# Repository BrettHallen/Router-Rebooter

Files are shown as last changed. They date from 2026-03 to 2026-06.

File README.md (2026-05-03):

# Router Rebooter
Simple device to reboot my router when the NBN (National Broadband Network) stops working.<br>

This is typically when we're away from home for more than a week which means that the RING cameras & WiFi-enabled lights & powerpoints (to make it look like we're home) stop working.<br>

Yes, yes, I shouldn't be using cloud-enabled devices which will get bricked at the manufacturer's whim.  I'll work on it.<br>

And yes, there are devices that do this - they seemed a bit pricey.<br>

## Idea
The broadband router I have is a Netcomm Wireless NF18ACV that runs on 12VDC.  We got it when we originally had FTTN (fibre to the node) which runs optical fibre to a street cabinet/node and then uses the decades-old telephone copper cabling to the house.  Where we live now has FTTP (fibre to the premises) where the optical fibre runs straight to the house.  The same router still works fine so have never replaced it.<br>

I'll use an ESP32-type device to ping a reliable Internet address every minute, say a well-known DNS address like 1.1.1.1.  The ESP32 will be powered from the 12V input supply via a 5V regulator.  The power to the router will run through an NC (normally closed) relay.<br>

If there is no response for a few consecutive pings then I'll energise the relay which switches to open and disconnects the 12V to the router.<br>

After a short delay I'll then de-energise the relay and power the router back on.<br>

After another short delay whilst the router reconnects (2-3min) I'll reconnect to the WiFi network and resume pinging.

## YouTube Videos
- [Part 1: Initial build & test](https://youtu.be/Fz1aSylL9KQ)
- [Part 2: Revised PCB & Improved Firmware](https://youtu.be/78il7RK1qrU)

## Examples
This is how it works using the serial port output - here we simulate the loss of Internet by using dummy IP addresses:<br>
```
>> Brett's Router Rebooter Starting!
   (2/Apr/2026)
>> Monitoring NF18ACV
>> Timer/retry settings (DEBUG):
   Ping timer .......... 10s
   Ping retries ........ 3
   Ping retry timer .... 5s
   Power cycle timer ... 30s
   Recovery delay ...... 120s
>> Hardware initialised: Router on, OK LED on, FAILURE LED off, Ping LED off.
!! [handleHttpClients] WiFi not connected, ignoring HTTP requests.
>> Connecting to WiFi network <RouterRebootTest> ...
>> Using static IP address <192.168.128.129>
>> WiFi status = 3 (successfully connected!)
>> Connected to <RouterRebootTest> with address <192.168.128.129>
>> HTTP status page started on port 80
   Open in browser: http://192.168.128.129
>> Syncing NTP time (pool.ntp.org) ... 02/Apr/2026 18:53:07 (AEDT)
>> Pinging 1.1.1.1          Cloudflare primary   ... OK!
>> Pinging 192.168.123.123  Dummy test failure   ... failed!
>> Pinging 1.0.0.1          Cloudflare secondary ... OK!
>> Pinging 192.168.123.123  Dummy test failure   ... failed!
>> Pinging 192.168.123.123  Dummy test failure   ... failed!
>> Pinging 192.168.123.123  Dummy test failure   ... failed!
>> Pinging 192.168.123.123  Dummy test failure   ... failed!
!! No response after retries, disconnecting router power.
>> Waiting 30s before reconnecting power ...
   30s
   25s
   20s
   15s
   10s
   5s
>> Powering router back on.
>> Waiting 120s before resuming monitoring ...
   120s
   105s
   90s
   75s
   60s
   45s
   30s
   15s
>> Router recovery finished – resuming monitoring.

... and so on ...
```
And this is what it does when the Internet is fine, which should be 99.9% of the time:
```

>> Brett's Router Rebooter Starting!
   (2/Apr/2026)
>> Monitoring NF18ACV
>> Timer/retry settings:
   Ping timer .......... 1s
   Ping retries ........ 5
   Ping retry timer .... 15s
   Power cycle timer ... 30s
   Recovery delay ...... 180s
>> Hardware initialised: Router on, OK LED on, FAILURE LED off, Ping LED off.
!! [handleHttpClients] WiFi not connected, ignoring HTTP requests.
>> Connecting to WiFi network <RouterRebootTest> ...
>> Using static IP address <192.168.128.129>
>> WiFi status = 3 (successfully connected!)
>> Connected to <RouterRebootTest> with address <192.168.128.129>
>> HTTP status page started on port 80
   Open in browser: http://192.168.128.129
>> Syncing NTP time (pool.ntp.org) ... 02/Apr/2026 20:26:19 (AEDT)
>> Pinging 1.1.1.1          Cloudflare primary   ... OK!
>> Pinging 1.0.0.1          Cloudflare secondary ... OK!
>> Pinging 8.8.8.8          Google primary       ... OK!
>> Pinging 8.8.4.4          Google secondary     ... OK!
>> Pinging 9.9.9.9          Quad9 primary        ... OK!
>> Pinging 149.112.112.112  Quad9 secondary      ... OK!
>> Pinging 4.2.2.1          Level 3 primary      ... OK!
>> Pinging 4.2.2.2          Level 3 secondary    ... OK!
>> Pinging 4.2.2.3          Level 3 tertiary     ... OK!
>> Pinging 208.67.222.222   OpenDNS primary      ... OK!
>> Pinging 208.67.220.220   OpenDNS secondary    ... OK!
>> Pinging 1.1.1.1          Cloudflare primary   ... OK!
>> Pinging 1.0.0.1          Cloudflare secondary ... OK!
>> Pinging 8.8.8.8          Google primary       ... OK!
>> Pinging 8.8.4.4          Google secondary     ... OK!

... and so on ...
```

## [Firmware (Arduino Sketch)](/Firmware)
Use the Arduino IDE to compile & transfer to the ESP32.<br>

### Versions
- [Tested version](/Router-Rebooter)
- [Experimental version](/Experimental_version)

Experimental version - seems to be working fine, testing ongoing:<br>
- added support to ping IP addresses as well as FQDNs

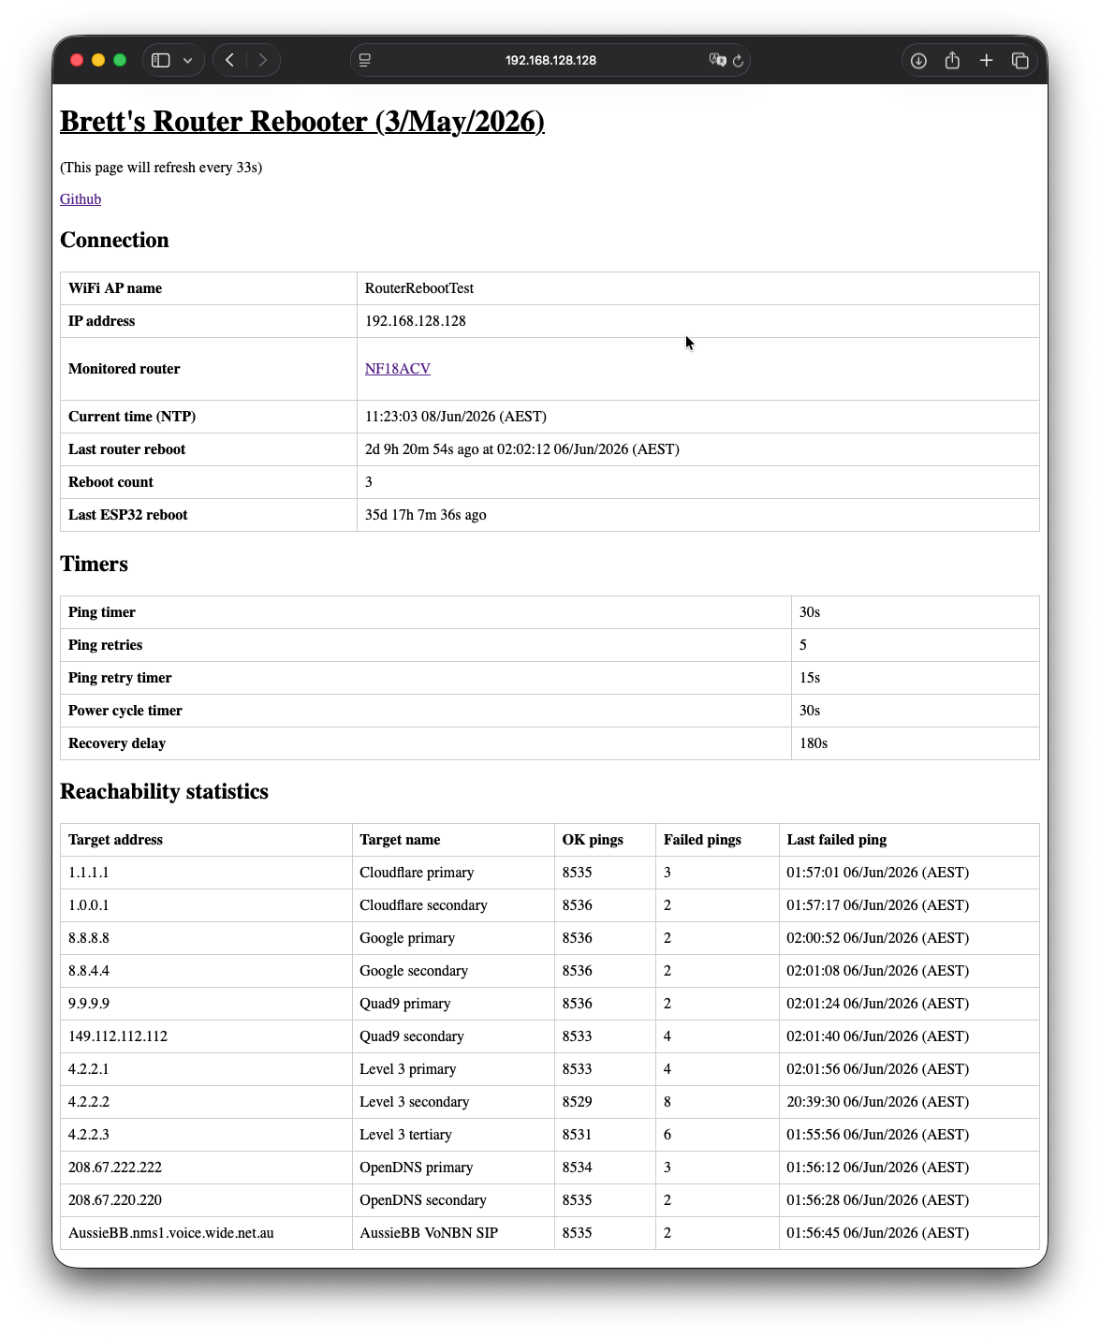
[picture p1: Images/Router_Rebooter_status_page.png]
Status page


### Required Libraries
Install via the Arduino IDE.
- [ESPping](https://github.com/dvarrel/ESPping)
- [Adafruit NeoPixel](https://github.com/adafruit/adafruit_neopixel)
- [Timezone](https://github.com/JChristensen/Timezone)

### Possible Improvements
- Send a message after the router has been rebooted (via CallMeBot to WhatsApp?)

## LED Status
There are three LEDs: the OK LED (suggested green), the FAILURE LED (suggested red) and the ESP32's built-in LED (RGB).<br>

| OK LED | FAILURE LED | ESP32 LED | Meaning |
|---|---|---|---|
| On | Off | Green/blue flashing | Connecting to WiFi |
| On | Off | Off | Everything ok, waiting to ping |
| On | Off | Blue pulse | Pinging |
| On | On | Red | Ping failed |
| Off | On | Off | Ping retries failed |
| Off | On | Green flashing | Router power cycling |
| Flashing | Flashing | Red/green flashing  | Waiting for router to recover  | 

## Hardware
There's currently two versions:
- [Rev. B](/KiCad/RevB) minor corrections of my original design with 2.1mm DC sockets and vertically mounted regulator 
- [Rev. D](/KiCad/RevC) removes the 2.1mm DC sockets, lies the 5V regulator down and adds regulator output bypass for the ESP32 when connected via serial/USB

### Parts
- OMRON GL5E-1-VD relay (or similar)
- ESP32-C3-Zero development board (Waveshare)
- 10µF capacitor for the ESP32 power - could probably be left off (short pins)
- One 7805-type 5V regulator (i.e. [EzSBC's PSU2-5](https://ezsbc.shop/products/psu2-5-5v-1amp-three-pin-regulator)) to power the ESP. I am using a switching regulator so don't have any provision for heatsinking a linear regulator.
- Two 2.1mm DC power sockets to pass through the 12VDC
- Some other bits (2N2222 transistor, 1KΩ resistor, 1N4148 diode) to connect the relay coil to the ESP32
- 2-pin header to disconnect 5V regulator when ESP32 is connected to USB for testing to avoid connecting two power supplies
- Four M3 screws to mount it somehow

I've sized the PCB (62x49mm) to fit an 83x54x31mm Jiffy Box [(Jaycar HB6015)](https://www.jaycar.com.au/jiffy-box-black-83-x-54-x-31mm/p/HB6015).<br>

Waveshare ESP32-C3-Zero symbol/footprint/3D model from:<br>
https://github.com/jonathanadams/KiCad-Waveshare-ESP32

## Images
### Rev A. version built
The green OK LED indicates normal operation of the router and the blue ESP32 LED indicates it's currently sending a test ping to test reachability.

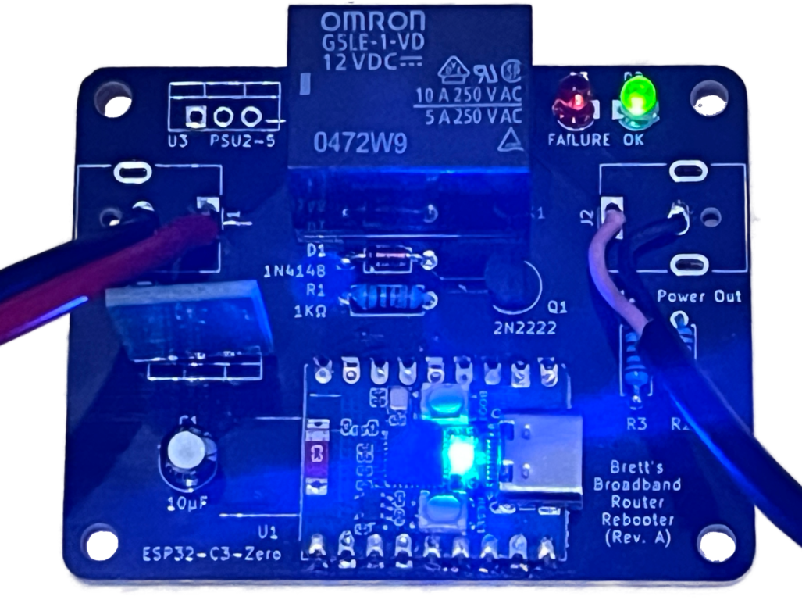
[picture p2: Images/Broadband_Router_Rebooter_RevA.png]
Rev A under test


### Rev. C version 3D rendering
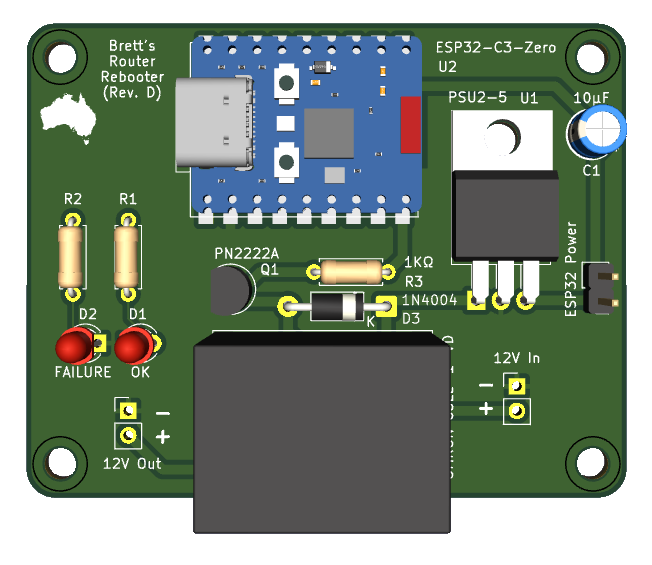
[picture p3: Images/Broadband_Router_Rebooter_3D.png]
Router Rebooter 3D


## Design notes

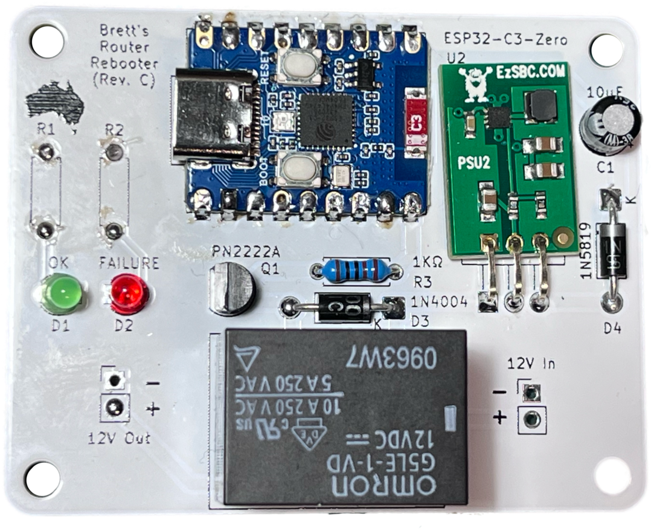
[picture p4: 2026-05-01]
Images/Broadband_Router_Rebooter_RevC.png

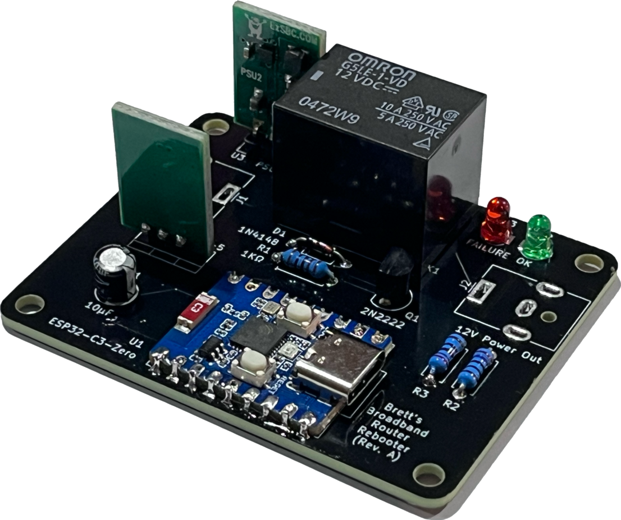
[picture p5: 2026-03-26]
Images/Broadband_Router_Rebooter_2_small.png

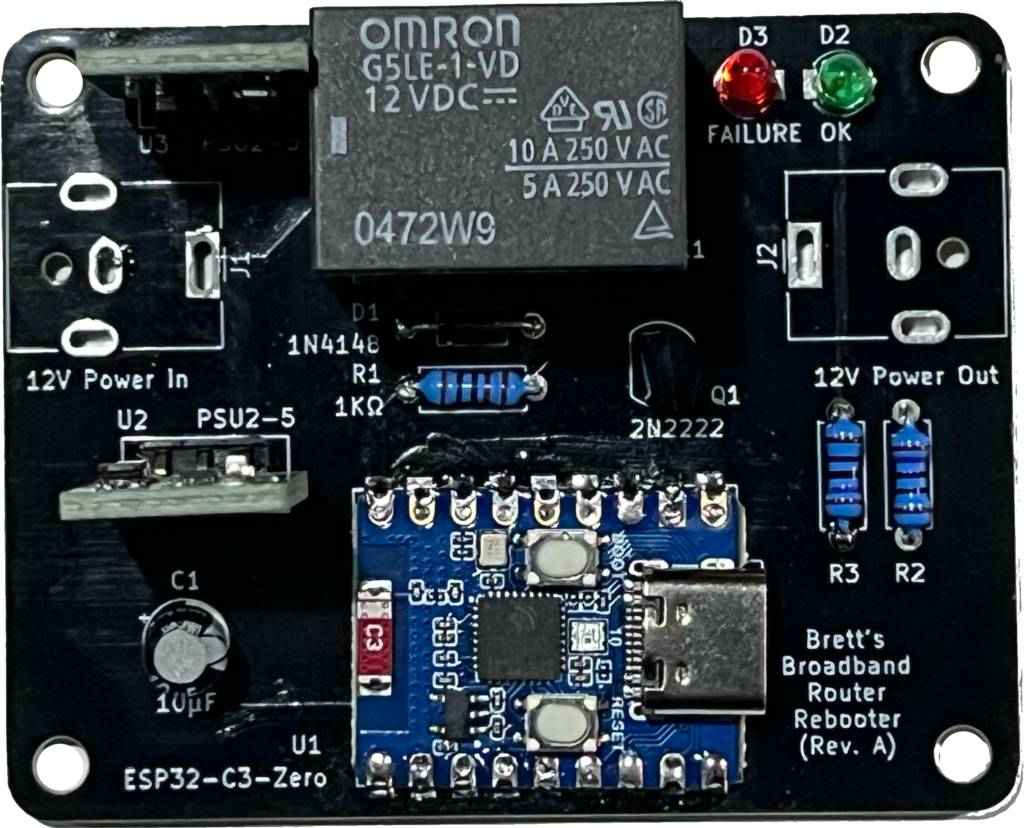
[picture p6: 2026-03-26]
Images/Broadband_Router_Rebooter_1_small.png

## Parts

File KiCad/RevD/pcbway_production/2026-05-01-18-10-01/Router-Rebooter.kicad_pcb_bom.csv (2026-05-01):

Designator | Quantity | Value | Footprint | Package | MPN | DNP | Mount_Type | Description | Sim.Pins | Sim.Device
C1 | 1 | 10µF | CP_Radial_D5.0mm_P2.50mm |  |  |  | tht | Polarized capacitor
D1 | 1 | OK | LED_D3.0mm |  |  |  | tht | Light emitting diode | 1=K 2=A
D2 | 1 | FAILURE | LED_D3.0mm |  |  |  | tht | Light emitting diode | 1=K 2=A
D3 | 1 | 1N4004 | D_DO-41_SOD81_P10.16mm_Horizontal |  |  |  | tht | Diode | 1=K 2=A | D
J1 | 1 | 12V Out | PinHeader_1x02_P2.54mm_Vertical |  |  |  | tht | Generic connector, single row, 01x02, script generated (kicad-library-utils/schlib/autogen/connector/)
J2 | 1 | ESP32 Power | PinHeader_1x02_P2.54mm_Vertical |  |  |  | tht | Generic connector, single row, 01x02, script generated (kicad-library-utils/schlib/autogen/connector/)
J3 | 1 | 12V In | PinHeader_1x02_P2.54mm_Vertical |  |  |  | tht | Generic connector, single row, 01x02, script generated (kicad-library-utils/schlib/autogen/connector/)
K1 | 1 | OMRON G5LE-1-VD | Relay_SPDT_Omron-G5LE-1 |  |  |  | tht | Sanyo SRD relay, Single Pole Miniature Power Relay, Opening Contact
Q1 | 1 | PN2222A | TO-92_Inline |  |  |  | tht | 1A Ic, 40V Vce, NPN Transistor, General Purpose Transistor, TO-92
R1, R2 | 2 | R | R_Axial_DIN0207_L6.3mm_D2.5mm_P7.62mm_Horizontal |  |  |  | tht | Resistor
R3 | 1 | 1KΩ | R_Axial_DIN0207_L6.3mm_D2.5mm_P7.62mm_Horizontal |  |  |  | tht | Resistor
U1 | 1 | PSU2-5 | TO-220-3_Horizontal_TabDown |  |  |  | tht | Positive 1A 35V Linear Regulator, Fixed Output 5V, TO-220
U2 | 1 | ESP32-C3-Zero | Waveshare-ESP32-C3-Zero |  |  |  | smt

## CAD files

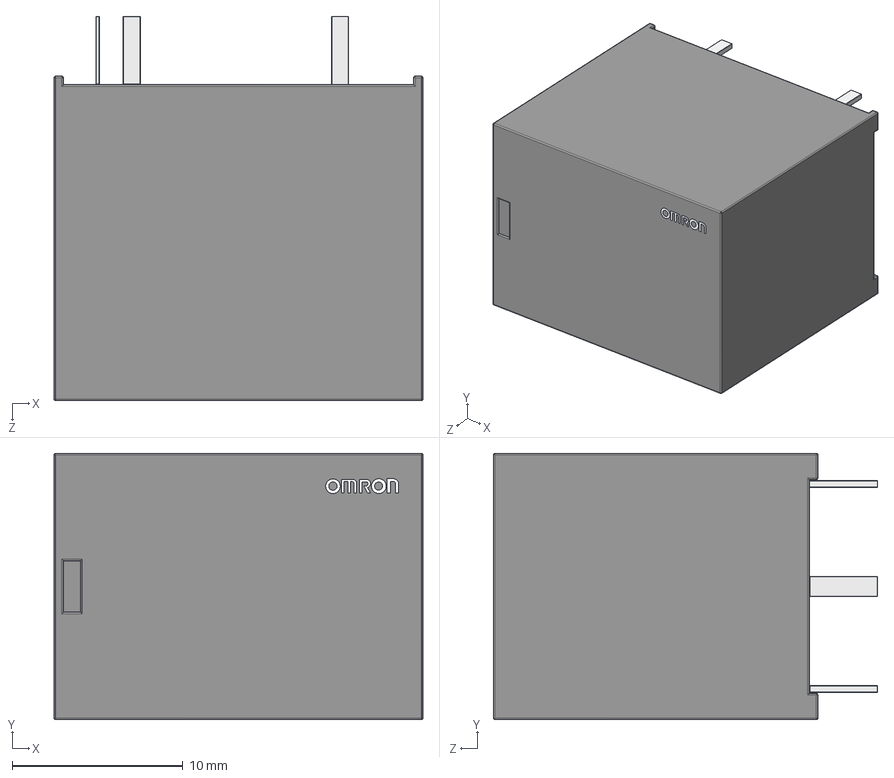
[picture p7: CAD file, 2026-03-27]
KiCad/Symbols/G5LE-1-VD_DC12.stp
21.6 x 15.6 x 22.5 mm
Omron

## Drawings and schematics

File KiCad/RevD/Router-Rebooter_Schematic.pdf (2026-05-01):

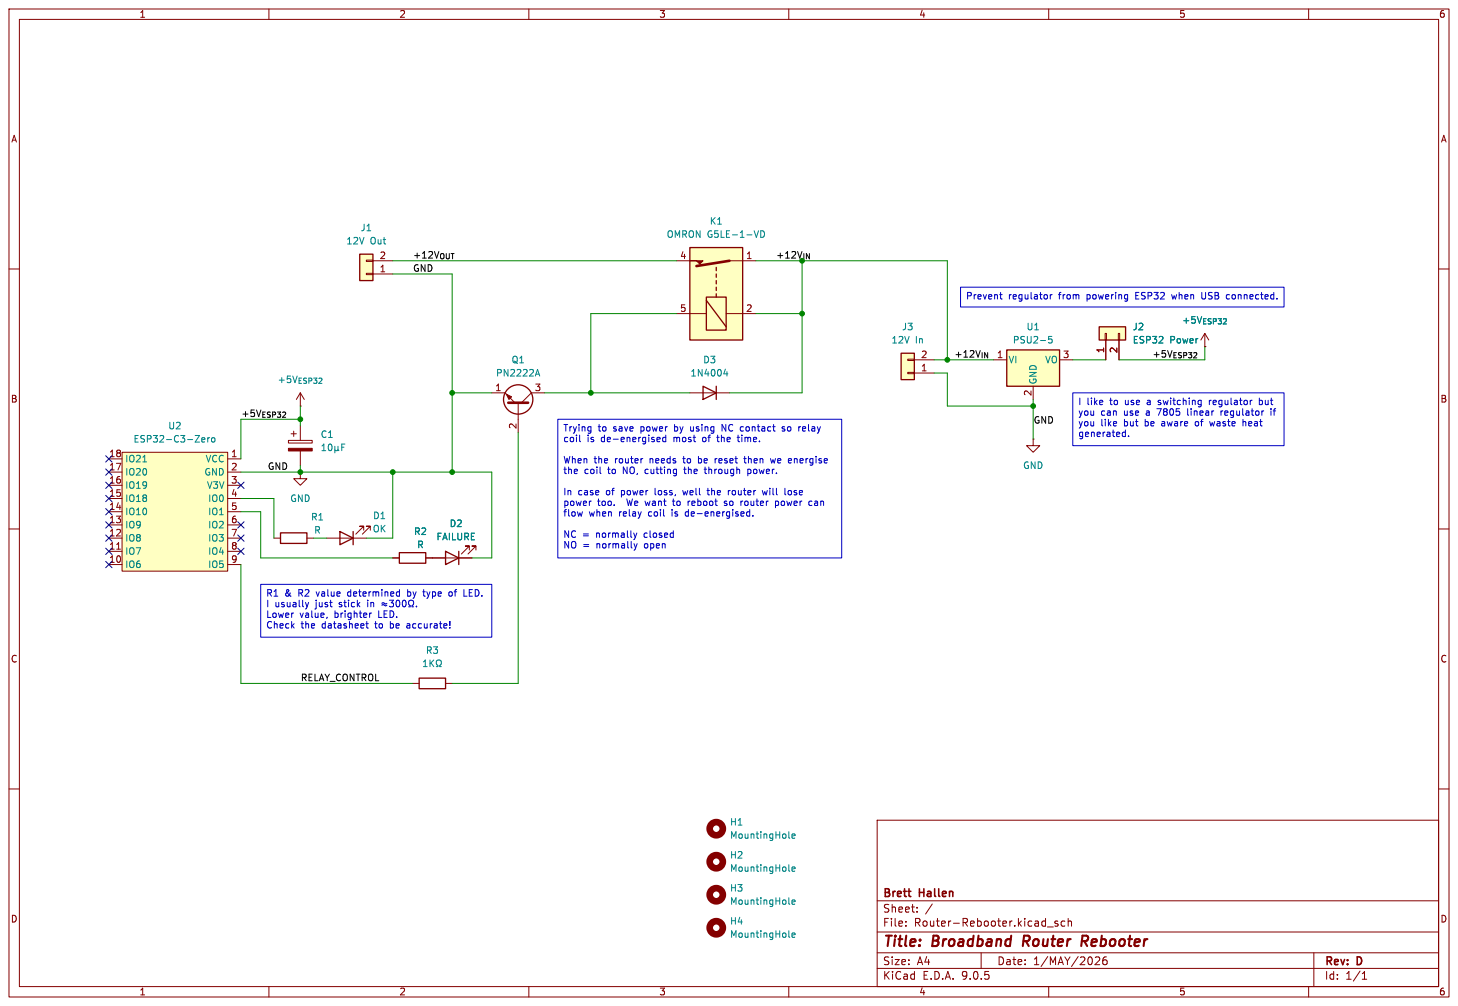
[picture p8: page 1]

In case of power loss, well the router will lose

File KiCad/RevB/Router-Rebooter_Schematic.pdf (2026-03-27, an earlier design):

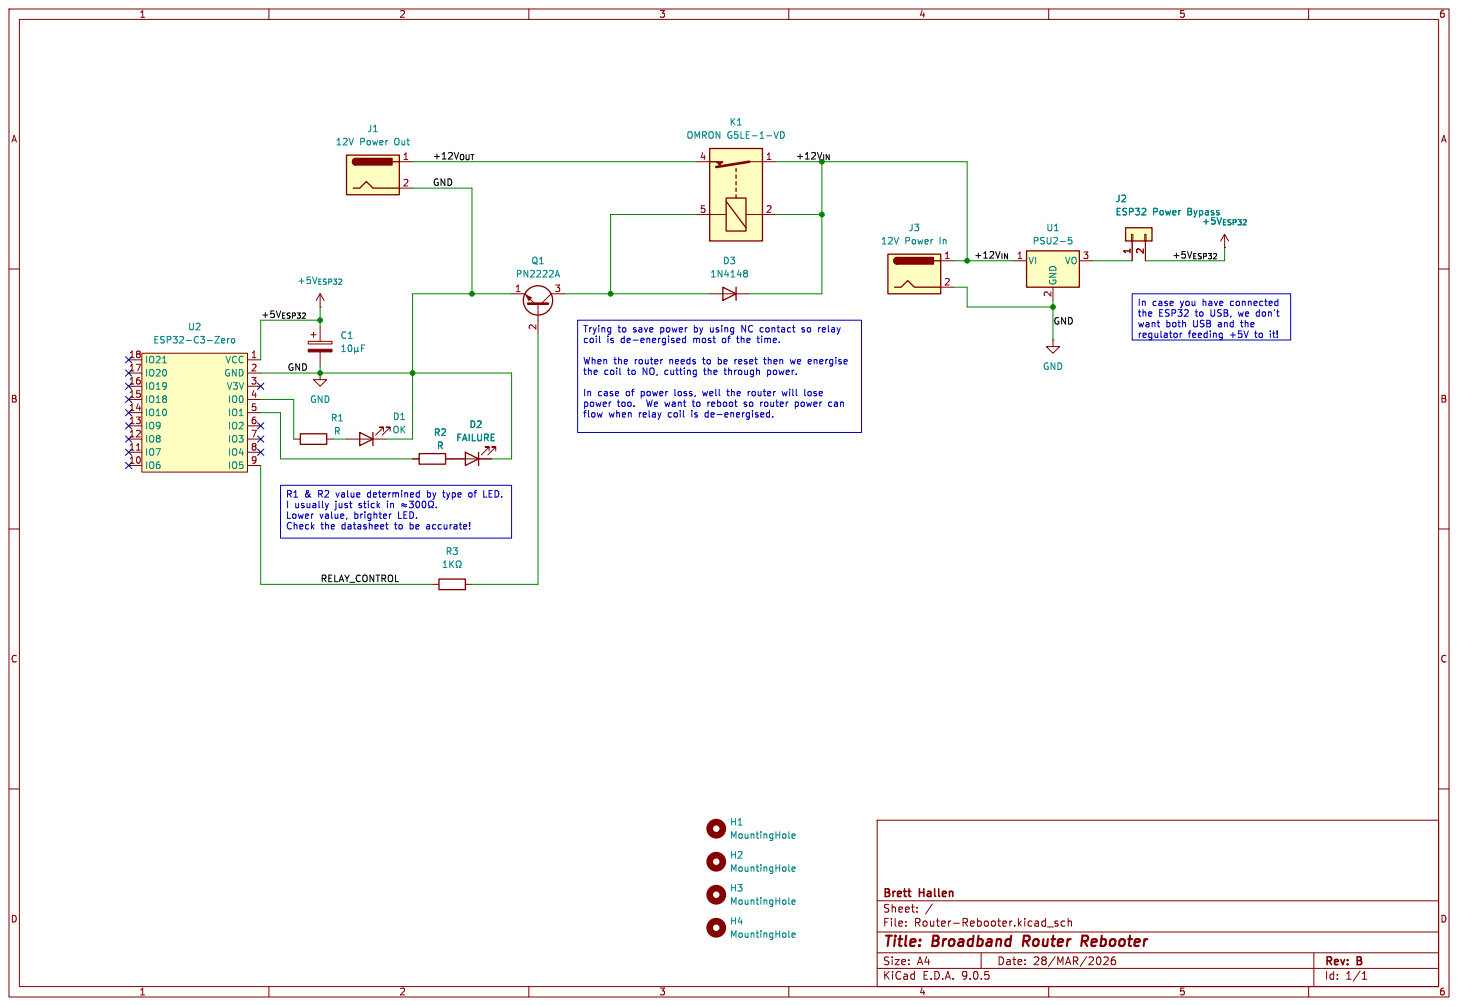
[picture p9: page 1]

12V Power In H1 MountingHole H2 MountingHole H3 MountingHole

2 VO 3 U1 PSU2-5 GND GND GND

In case you have connected
the ESP32 to USB, we don't want both USB and the

In case of power loss, well the router will lose
flow when relay coil is de-energised.

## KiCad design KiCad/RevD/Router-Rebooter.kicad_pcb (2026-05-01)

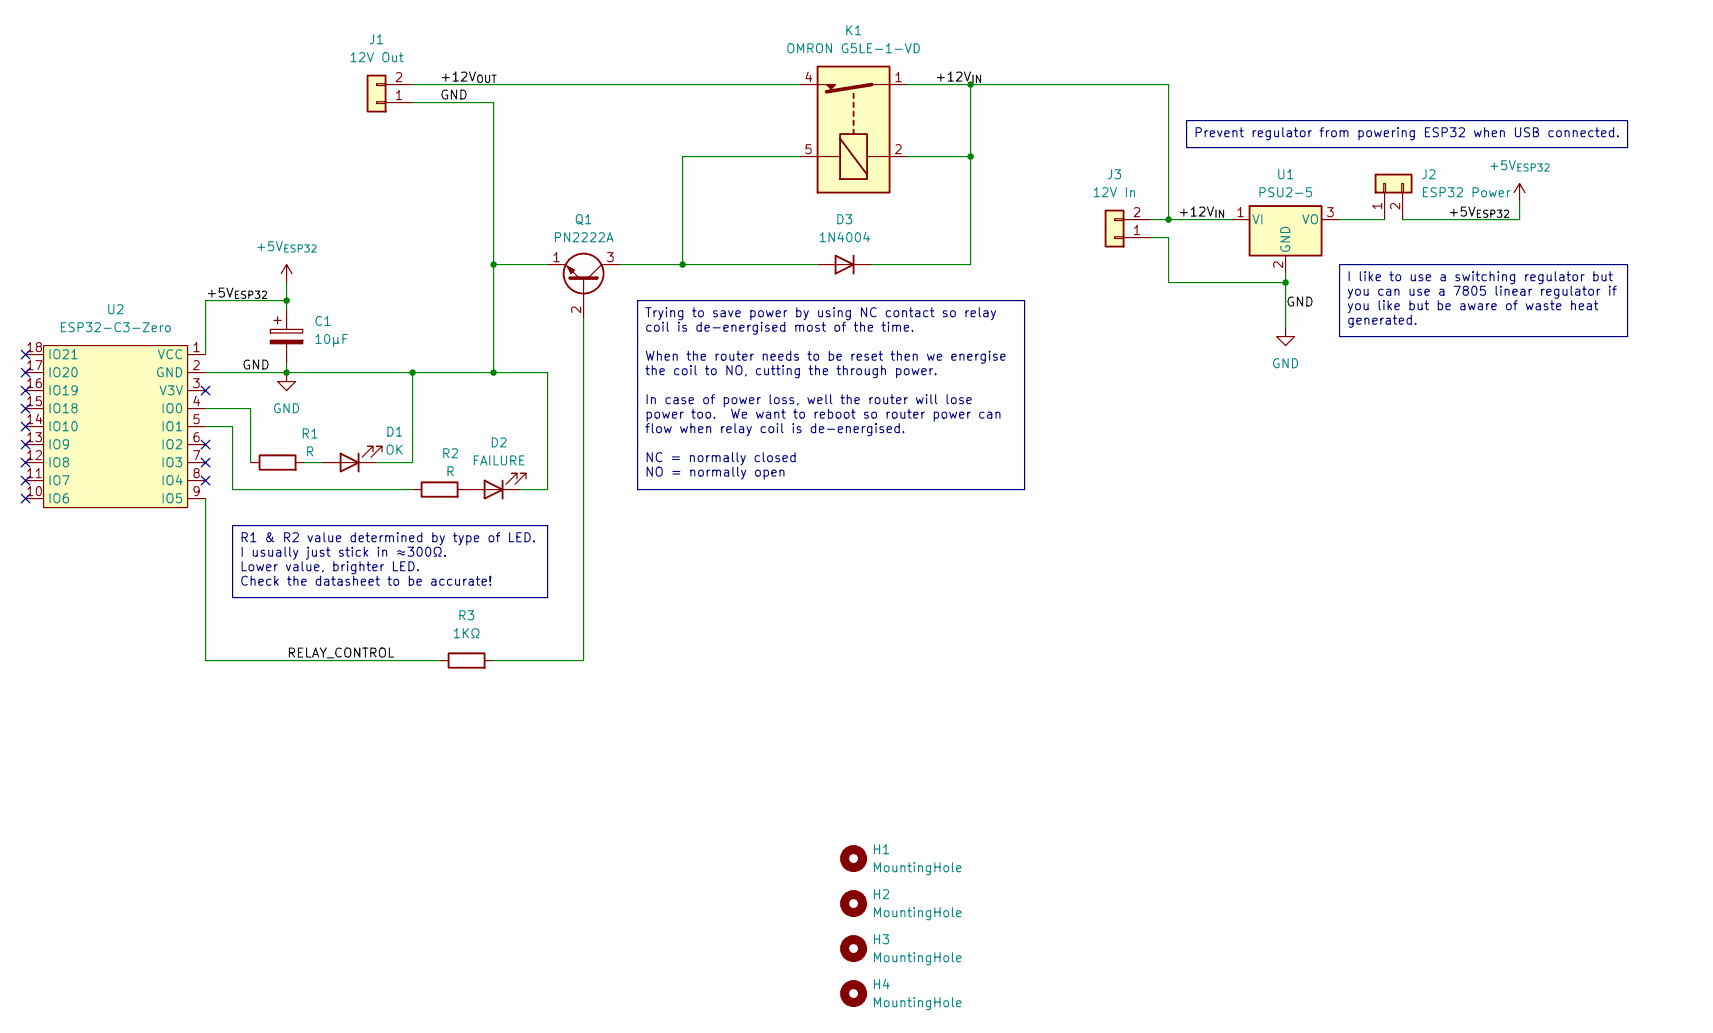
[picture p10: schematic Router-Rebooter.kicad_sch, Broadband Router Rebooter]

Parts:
C1: 10µF; CP_Radial_D5.0mm_P2.50mm
D1: OK; LED_D3.0mm
D2: FAILURE; LED_D3.0mm
D3: 1N4004; D_DO-41_SOD81_P10.16mm_Horizontal
H1, H2, H3, H4: MountingHole; MountingHole_3.2mm_M3_DIN965
J1: 12V Out; PinHeader_1x02_P2.54mm_Vertical
J2: ESP32 Power; PinHeader_1x02_P2.54mm_Vertical
J3: 12V In; PinHeader_1x02_P2.54mm_Vertical
K1: OMRON G5LE-1-VD; Relay_SPDT_Omron-G5LE-1
Q1: PN2222A; TO-92_Inline
R1, R2: R; R_Axial_DIN0207_L6.3mm_D2.5mm_P7.62mm_Horizontal
R3: 1KΩ; R_Axial_DIN0207_L6.3mm_D2.5mm_P7.62mm_Horizontal
U1: PSU2-5; TO-220-3_Horizontal_TabDown
U2: ESP32-C3-Zero; Waveshare-ESP32-C3-Zero

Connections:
+5V_{ESP32}: C1.1, J2.2, U2.1 (VCC)
/+12V_{IN}: D3.1 (K), J3.2, K1.1, K1.2, U1.1 (VI)
/+12V_{OUT}: J1.2, K1.4
/RELAY_CONTROL: R3.1, U2.9 (IO5)
GND: C1.2, D1.1 (K), D2.1 (K), J1.1, J3.1, Q1.1 (E), U1.2 (GND), U2.2 (GND)
unnamed: D1.2 (A), R1.2
unnamed: D2.2 (A), R2.2
unnamed: D3.2 (A), K1.5, Q1.3 (C)
unnamed: J2.1, U1.3 (VO)
unnamed: Q1.2 (B), R3.2
unnamed: R1.1, U2.4 (IO0)
unnamed: R2.1, U2.5 (IO1)

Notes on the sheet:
R1 & R2 value determined by type of LED. I usually just stick in ≈300Ω. Lower value, brighter LED. Check the datasheet to be accurate!
I like to use a switching regulator but you can use a 7805 linear regulator if you like but be aware of waste heat generated.
Prevent regulator from powering ESP32 when USB connected.
Trying to save power by using NC contact so relay coil is de-energised most of the time. When the router needs to be reset then we energise the coil to NO, cutting the through power. In case of power loss, well the router will lose power too. We want to reboot so router power can flow when relay co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

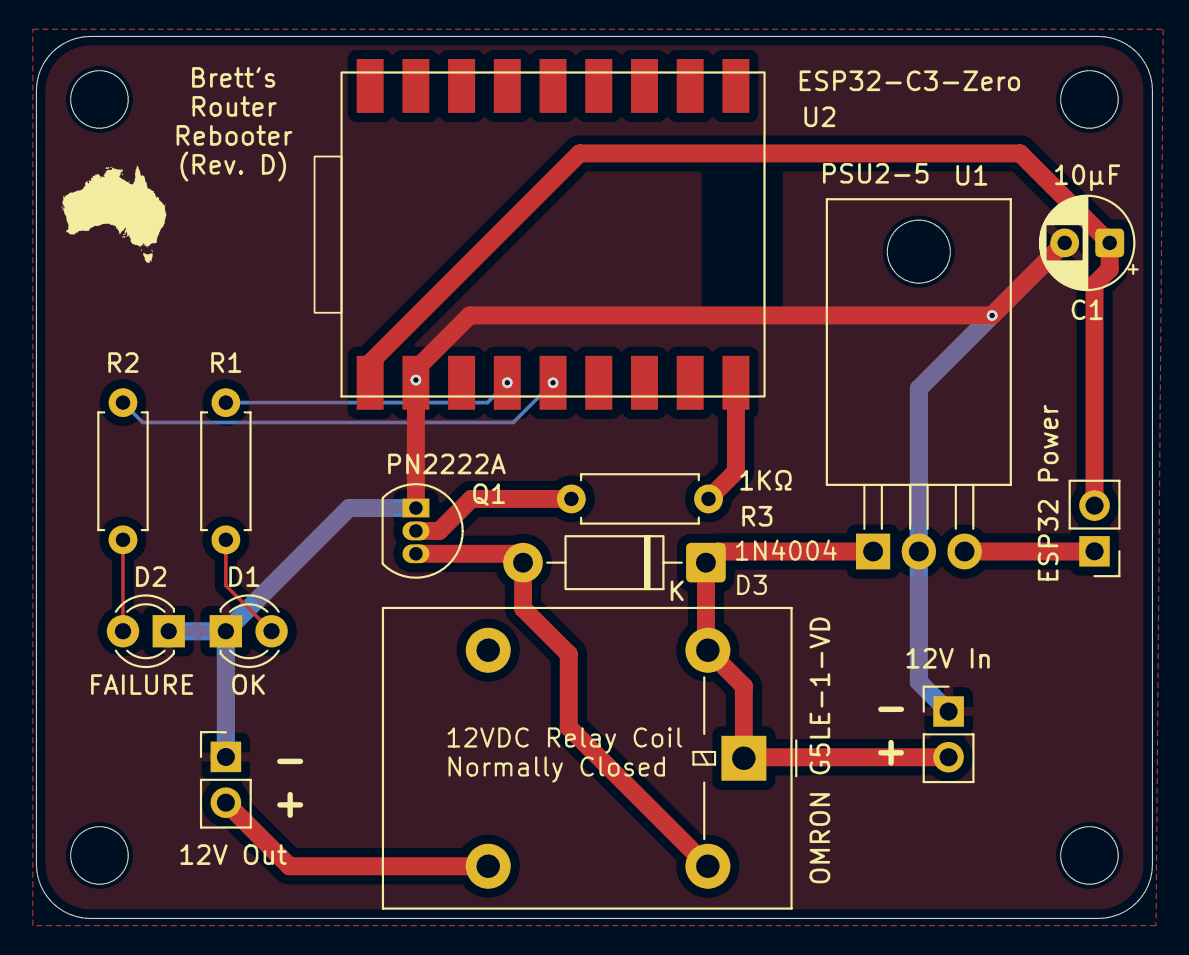
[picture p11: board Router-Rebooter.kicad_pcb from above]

Board: 2 copper layers, 62.0 x 49.0 mm, 18 parts (0 on the bottom side), 12 nets.

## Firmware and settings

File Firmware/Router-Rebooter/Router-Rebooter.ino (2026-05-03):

/***********************************************************************/
/* Router Rebooter for ESP32-C3-Zero                                   */
/*                                                                     */
/* Brett Hallen, 26/Mar/2026: initial                                  */
/*               27/Mar/2026: round-robin pinging                      */
/*               28/Mar/2026: ESP32 LED                                */
/*               29/Mar/2026: Static IP, HTTP stats/status page        */
/*               30/Mar/2026: added DNS names, NTP time keeping        */
/*               31/Mar/2026: code cleanup & commenting                */
/*                            added F() macro to reduce RAM/heap use   */
/*                1/Apr/2026: added Github link to status page         */
/*                2/Apr/2026: added TZ/DST support                     */
/*                5/Apr/2026: added reboot count & other minor tweaks  */
/*               16/Apr/2026: fixed UTC-AEDT conversion                */
/*                            calculate MIN_VALID_TIME at compile time */
/*                3/May/2026: "Reachability" typo (thanks Brian!)      */
/*                            also ping FQDNs                          */
/*                                                                     */
/* HARDWARE MAPPING:                                                   */
/*   Relay control: GPIO 5 (pin 9) via 2N2222 transistor               */
/*                  active HIGH to energise                            */
/*   OK LED:        GPIO 0 (pin 4)                                     */
/*   FAILURE LED:   GPIO 1 (pin 5)                                     */
/*                                                                     */
/* RELAY BEHAVIOR:                                                     */
/*   NC contact used, coil de-energised most of the time (router on)   */
/*   Only energise coil when we need to cut power (reboot)             */
/*                                                                     */
/* LED BEHAVIOUR:                                                      */
/*   OK LED:      steady when router is okay,                          */
/*                flashing when recovery in progress                   */
/*   FAILURE LED: steady when pinging has failed                       */
/*   ESP32:       flashes blue when pinging,                           */
/*                red when ping failed,                                */
/*                flashes green during recovery                        */
/*                blue/green when connecting to WiFi                   */
/***********************************************************************/

/* Required Arduino libraries **********************************************************************/
#include <WiFi.h>                /* Wonder what this is for                                        */
#include <ESPping.h>             /* Required for pings                                             */
#include <Adafruit_NeoPixel.h>   /* Required for the WS2812 RGB LED on the Waveshare ESP32-C3-Zero */
#include <time.h>                /* Required for NTP real-time clock support                       */
#include <Timezone.h>            /* Required for TZ and DST support                                */
/***************************************************************************************************/

/* CUSTOMISATIONS ******************************************************************/
/* DEBUG_MODE ........... Shorter timers & dodgy addresses to test the monitioring */
/* STATIC_IP  ........... set a static IP address to make it easier to find the    */
/*                        HTTP status page                                         */
/* NTP configuration .... If you want time stamps                                  */
/* formatNTPTime ........ Customise the timestamp output format if you like        */
/* WIFi configuration ... Obviously very important, configure your home WiFi here  */
/* dnsList & dnsName .... List of target IP addresses/names to test reachability   */
/*                        to, customise if you want!                               */
/* myRouter ............. Just a name to help identify the rebooter                */
/* myRouterAdminPage .... If you want a link on the status page                    */
/***********************************************************************************/

/* Uncomment for debug/testing ***********************/
//#define DEBUG_MODE   /* Testing settings or normal */
/*****************************************************/

/* Static IP address **************************************************/
#define STATIC_IP    /* Assign yourself an IP address for easy access */
/**********************************************************************/

/* Status page settings *******************************************************************/
const char* versionDate = "3/May/2026";                  /* Version date of this firmware */
const char* myRouter = "NF18ACV";                       /* Customise to help identify me! */
const char* myRouterAdminPage = "http://192.168.1.1"; /* Admin/login page for your router */
//const char* myRouterAdminPage = "";              /* No admin/login page for your router */
const char* githubRepo = "https://github.com/BrettHallen/Router-Rebooter";   /* My Github */
/******************************************************************************************/

/* Static IP configuration **********************************************************/
#ifdef STATIC_IP 
  const IPAddress staticIP(192, 168, 128, 128);   /* Your static IP address         */
//const IPAddress staticIP(192, 168, 128, 129);   /* For testing 2nd rebooter       */
  const IPAddress gateway(192, 168, 1, 1);        /* Your router/gateway IP address */
  const IPAddress subnet(255, 255, 0, 0);         /* Your netmask                   */
  const IPAddress dns(1, 1, 1, 1);                /* DNS IP address                 */
#endif
/************************************************************************************/

/* WiFi configuration **************************************************/
const char* ssid     = "RouterRebootTest";  /* Your WiFi SSID here     */
const char* password = "Today123!";         /* Your WiFi password here */
/***********************************************************************/

/* NTP & TZ configuration *********************************************************************************/
const char* ntpServer = "pool.ntp.org";                      /* NTP server                                */
bool ntpSyncInProgress = false;                              /* To prevent serial logs                    */
/* TZ/DST setting for NSW, Australia **********************************************************************/
TimeChangeRule myDST = {"AEDT", First, Sun, Oct, 2, 660};    /* GMT+11 hours from 02:00 first Sunday Oct  */
TimeChangeRule mySTD = {"AEST", First, Sun, Apr, 3, 600};    /* GMT+10 hours from 03:00 first Sunday Apr  */
/* Example: TZ setting for non-DST location, i.e. QLD, Australia ******************************************/
// TimeChangeRule myDST = {"AEST", First, Sun, Jan, 0, 600}; /* Always GMT+10                             */
// TimeChangeRule mySTD = {"AEST", First, Sun, Jan, 0, 600}; /* Always GMT+10                             */
/**********************************************************************************************************/
Timezone myTZ(myDST, mySTD);                                 /* Create the timezone object                */
const char* previousTZAbbrev = "";                           /* For serial log to detect when DST changed */
bool ntpTimeSynced = false;                                  /* True after first successful NTP sync      */
/**********************************************************************************************************/
//#define MIN_VALID_TIME  1776297600UL     /* 16/Apr/2026 ... ensure only reasonable timestamps are shown */
/**********************************************************************************************************/

/*******************************************/
/* Generate MIN_VALID_TIME at compile time */
/* to ensure sane timestamps               */
/*******************************************/
#define COMPILE_YEAR   ((__DATE__[7]-'0')*1000 + (__DATE__[8]-'0')*100 + (__DATE__[9]-'0')*10 + (__DATE__[10]-'0'))
#define COMPILE_MONTH  ( __DATE__[0]=='J' && __DATE__[1]=='a' && __DATE__[2]=='n' ? 1 : \
                         __DATE__[0]=='F' ? 2 : \
                         __DATE__[0]=='M' && __DATE__[1]=='a' && __DATE__[2]=='r' ? 3 : \
                         __DATE__[0]=='A' && __DATE__[1]=='p' ? 4 : \
                         __DATE__[0]=='M' && __DATE__[1]=='a' && __DATE__[2]=='y' ? 5 : \
                         __DATE__[0]=='J' && __DATE__[1]=='u' && __DATE__[2]=='n' ? 6 : \
                         __DATE__[0]=='J' && __DATE__[1]=='u' && __DATE__[2]=='l' ? 7 : \
                         __DATE__[0]=='A' && __DATE__[1]=='u' ? 8 : \
                         __DATE__[0]=='S' ? 9 : \
                         __DATE__[0]=='O' ? 10 : \
                         __DATE__[0]=='N' ? 11 : 12)
#define COMPILE_DAY    ((__DATE__[4]==' ' ? 0 : __DATE__[4]-'0')*10 + (__DATE__[5]-'0'))
#define MIN_VALID_TIME (((time_t)(COMPILE_YEAR - 1970) * 31536000UL) + \
                        ((COMPILE_YEAR - 1969)/4 * 86400UL) - \
                        ((COMPILE_YEAR - 1901)/100 * 86400UL) + \
                        ((COMPILE_YEAR - 1601)/400 * 86400UL) + \
                        0UL)

/* Ping both IP addresses and FQDNs */
struct PingTarget 
{
  const char* address;   /* Target IP string or FQDN               */
  const char* name;      /* Target description                     */
  bool isHostname;       /* true = resolve as hostname, false = IP */
};

#ifdef DEBUG_MODE
  /*****************************************************/
  /* Round-robin DNS list                              */
  /* DEBUG mode – includes dummy IPs to force failures */
  /*****************************************************/
  const PingTarget targets[] = 
  {
    {"1.1.1.1",                         "Cloudflare primary",   false},
    {"192.168.123.123",                 "Dummy test failure1",  false},
    {"8.8.8.8",                         "Google primary",       false},
    {"192.168.123.123",                 "Dummy test failure2",  false},
    {"192.168.123.123",                 "Dummy test failure3",  false},
    {"192.168.123.123",                 "Dummy test failure4",  false},
    {"192.168.123.123",                 "Dummy test failure5",  false},
    {"192.168.123.123",                 "Dummy test failure6",  false},
    {"AussieBB.nms1.voice.wide.net.au", "AussieBB Voice NMS",   true}  /* for VoNBN */
  };
  /* Timers for testing ***************************************************/
  const int PING_TIMER       = 10000; /* Delay between normal pings (ms)  */
  const int PING_RETRIES     = 3;     /* Retry ping before failing        */
  const int PING_RETRY_TIMER = 5000;  /* Delay between retries (ms)       */
  const int POWER_CYCLE_TIME = 30;    /* Delay for power cycling (s)      */
  const int RECOVERY_DELAY   = 120;   /* Delay after powering back on (s) */
  /*************************************************************************/
#else
  /*****************************************************/
  /* Round-robin DNS list                              */
  /*****************************************************/
  const PingTarget targets[] = 
  {
    {"1.1.1.1",                         "Cloudflare primary",   false},
    {"1.0.0.1",                         "Cloudflare secondary", false},
    {"8.8.8.8",                         "Google primary",       false},
    {"8.8.4.4",                         "Google secondary",     false},
    {"9.9.9.9",                         "Quad9 primary",        false},
    {"149.112.112.112",                 "Quad9 secondary",      false},
    {"4.2.2.1",                         "Level 3 primary",      false},
    {"4.2.2.2",                         "Level 3 secondary",    false},
    {"4.2.2.3",                         "Level 3 tertiary",     false},
    {"208.67.222.222",                  "OpenDNS primary",      false},
    {"208.67.220.220",                  "OpenDNS secondary",    false},
    {"AussieBB.nms1.voice.wide.net.au", "AussieBB VoNBN SIP",   true}  /* for Aussie Broadband VoNBN */
  };
  /* Timers ***************************************************************/
  const int PING_TIMER       = 30000; /* Delay between normal pings (ms)  */
  const int PING_RETRIES     = 5;     /* Retry ping before failing        */
  const int PING_RETRY_TIMER = 15000; /* Delay between retries (ms)       */
  const int POWER_CYCLE_TIME = 30;    /* Delay for power cycling (s)      */
  const int RECOVERY_DELAY   = 180;   /* Delay after powering back on (s) */
  /************************************************************************/
#endif
const int NUM_TARGETS = sizeof(targets) / sizeof(targets[0]); /* Count of ping targets */
int currentTargetIndex = 0;                                       /* Round-robin index */

/* Ping statistics for each DNS address ****************************************************/
uint32_t okCount[NUM_TARGETS]        = {0}; /* How many OK pings                               */
uint32_t failCount[NUM_TARGETS]      = {0}; /* How many failed pings                           */
time_t   lastFailedPing[NUM_TARGETS] = {0}; /* Timestamp of last failed ping                   */
uint32_t lastRebootTime          = 0;   /* millis() when last router reboot occurred       */
time_t   lastRebootNTP           = 0;   /* NTP timestamp of last router reboot (0 = never) */
uint32_t rebootCount             = 0;   /* How many router reboots                         */
uint32_t esp32UpTime             = 0;   /* millis() since last ESP32 restart               */
/*******************************************************************************************/

/* GPIO pins ****************************************************************************/
const int RELAY_PIN        = 5;   /* GPIO5, active HIGH via 2N2222                      */
const int OK_LED_PIN       = 0;   /* GPIO0                                              */
const int FAILURE_LED_PIN  = 1;   /* GPIO1                                              */
const int BUILTIN_LED_PIN  = 10;  /* WS2812 RGB LED on GPIO10 (Waveshare ESP32-C3-Zero) */
#define RELAY_ENERGISE     HIGH   /* Energise coil = cut power to router (NO contact)   */
#define RELAY_DEENERGISE   LOW    /* De-energise coil = restore power (NC contact)      */
/****************************************************************************************/

/*****************************************************/
/* Circular buffer for the last 15 serial debug logs */
/* Not currently used, maybe later                   */
// const int MAX_LOG_LINES = 15;
// String logBuffer[MAX_LOG_LINES];
// int logHead = 0;
/*****************************************************/

/* Avoid kernel panic after router reboot if HTTP status page is active */
bool rebootInProgress = false;

/* NeoPixel object for the built-in RGB LED */
Adafruit_NeoPixel pixels(1, BUILTIN_LED_PIN, NEO_GRB + NEO_KHZ800);

/* HTTP server on port 80 for status/statistics */
WiFiServer httpServer(80);

/**************************************/
/* Print WiFi connection error status */
/**************************************/
void printWiFiStatus()
{
  int status = WiFi.status();

  if (status != WL_CONNECTED)
  {
    Serial.print("!! WiFi status = ");
    Serial.print(status);
    Serial.print(" (");

    switch (status)
    {
      case WL_IDLE_STATUS:
        Serial.println("idle, not attempting to connect)");
        break;
      case WL_NO_SSID_AVAIL:
        Serial.println("SSID not found, check network name/range?)");
        break;
      case WL_CONNECT_FAILED:
        Serial.println("connection failed, wrong password/auth. issue?)");
        break;
      case WL_CONNECTION_LOST:
        Serial.println("connection lost)");
        break;
      case WL_DISCONNECTED:
        Serial.println("disconnected, also check SSID and/or password)");
        break;
      case WL_NO_SHIELD:
        Serial.println("I somehow have no WiFi hardware!)");
        break;
      default:
        Serial.println("unknown error)");
        break;
    }
  }
  else
  {
    Serial.println(">> WiFi status = 3 (successfully connected!)");
  }
}
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
void loop() 
{
  /* Check for browser requests at the start of every loop */
  handleHttpClients(); 

  /* Reconnect after every power-cycle */
  connectToWiFi();

  /* Allow HTTP GET requests again (kernel panic otherwise) */
  rebootInProgress = false;
  while (true) 
  {
    /* Keep the web page responsive inside the monitoring loop */
    handleHttpClients(); 

    /* Daily NTP re-sync at 05:00 local time */
    const char* dummy = nullptr;
    time_t local = getLocalTimeWithAbbrev(&dummy);
    struct tm timeinfo;
    localtime_r(&local, &timeinfo);   // use local time
    if (getLocalTime(&timeinfo)) 
    {
      static bool syncedToday = false;
      if (timeinfo.tm_hour == 5 && timeinfo.tm_min == 0 && !syncedToday) 
      {
        syncNTPTime();
        syncedToday = true;
      }
      if (timeinfo.tm_hour != 5) syncedToday = false;
    }

    /* We lost our WiFi connecting, try to re-connect */
    if (WiFi.status() != WL_CONNECTED) 
    {
      Serial.println("!! WiFi lost – reconnecting ...");
      printWiFiStatus(); 
      break;
    }

    /* Test our Internet reachability */
    if (performPing()) 
    {
      setNormalState();

      /* Non-blocking so HTTP requests are handled quickly */
      waitWithHttpCheck(PING_TIMER);
      continue;
    }

    /* The last ping failed, indicate via LEDs */
    setFailureState();

    /* Start ping re-tries */
    bool recovered = false;
    for (int i = 0; i < PING_RETRIES; i++) 
    {
      /* Non-blocking so HTTP requests are handled quickly */
      waitWithHttpCheck(PING_RETRY_TIMER);
      if (performPing()) 
      {
        recovered = true;
        break;
      }
    }

    /* Next ping was successful, phew! */
    if (recovered) 
    {
      setNormalState();

      /* Non-blocking so HTTP requests are handled quickly */
      waitWithHttpCheck(PING_TIMER); 
      continue;
    }

    /* Still dead after retries, power cycle */
    rebootInProgress = true; /* Needed to avoid kernel panic after router power cycling & WiFi disconnect/reconnect */
    httpServer.stop();       /* ... and this */
    Serial.println("!! No response after retries, disconnecting router power.");
    /* Energise the relay ... opens ... disconnect router power */
    digitalWrite(RELAY_PIN, RELAY_ENERGISE);
    pixels.setPixelColor(0, pixels.Color(0, 0, 0));
    pixels.show();

    /* Record both millis and timestamp */
    lastRebootTime = millis();
    lastRebootNTP = time(NULL); /* Store as GMT/UTC, not local time */
    rebootCount++;

    /* Keep router off for a short period to ensure we clear everything from RAM */
    Serial.print(">> Waiting "); Serial.print(POWER_CYCLE_TIME); Serial.println("s before reconnecting power ...");
    int COUNT_DOWN_STEP = 5; /* Update every 5s */
    for (int seconds = POWER_CYCLE_TIME; seconds > 0; seconds-=COUNT_DOWN_STEP)
    {
      /* Keep web page alive during countdown - REMOVED due to kernel panics during WiFi reconnect */
      // handleHttpClients(); 
      Serial.print("   "); Serial.print(seconds); Serial.println("s");
      for (int i = 0; i < COUNT_DOWN_STEP; i++)
      {
        /* This accounts for 1s */
        pixels.setPixelColor(0, pixels.Color(255, 0, 0));
        pixels.show();
        delay(500); /* 500ms */
        pixels.setPixelColor(0, pixels.Color(0, 0, 0));
        pixels.show();
        delay(500); /* 500ms */
      }
    }
    Serial.println(">> Powering router back on.");
    digitalWrite(RELAY_PIN, RELAY_DEENERGISE);

    /* Wait for router to re-connect to ISP before resuming monitoring */
    Serial.print(">> Waiting "); Serial.print(RECOVERY_DELAY); Serial.println("s before resuming monitoring ...");
    for (int seconds = RECOVERY_DELAY; seconds > 0; seconds-=(COUNT_DOWN_STEP*3)) /* Update every 15s */
    {
      /* Keep web page alive during countdown - REMOVED due to kernel panics during WiFi reconnect */
      // handleHttpClients(); 
      Serial.print("   ");  Serial.print(seconds);  Serial.println("s");
      for (int i = 0; i < (COUNT_DOWN_STEP*3); i++) 
      {
        /* This accounts for 1s */
        digitalWrite(OK_LED_PIN, HIGH);                   /* OK on       */
        digitalWrite(FAILURE_LED_PIN, LOW);               /* FAILURE off */
        pixels.setPixelColor(0, pixels.Color(255, 0, 0)); /* Green       */
        pixels.show();
        delay(500); /* 500ms */
        digitalWrite(OK_LED_PIN, LOW);                    /* OK off     */
        digitalWrite(FAILURE_LED_PIN, HIGH);              /* FAILURE on */
        pixels.setPixelColor(0, pixels.Color(0, 255, 0)); /* Red        */
        pixels.show();
        delay(500); /* 500ms */
      }
    }

    Serial.println(">> Router recovery finished – resuming monitoring.");
    Serial.println();
    Serial.println();

    setNormalState();
    
    WiFi.disconnect(true);
    delay(2000); /* 2s */
    break;
  }
}

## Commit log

2026-01-22 Added indicator LEDs (OK & FAILURE)
    OK is steady green when everything is okay
    FAILURE is flashing red when rebooting
    [Router-Rebooter.kicad_pcb, Router-Rebooter.kicad_pcb_bom.csv, Router-Rebooter.kicad_pcb_positions.csv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]
2026-03-26 Initial built version for testing
    [Router-Rebooter.kicad_pcb_bom.csv, Router-Rebooter.kicad_pcb_positions.csv]
2026-03-26 Cosmetic changes
    [Router-Rebooter.kicad_pcb, Router-Rebooter.kicad_sch]
2026-03-26 Initial version of ESP32-C3-Zero code
2026-03-27 Corrected schematic/footprint errors
    [Router-Rebooter.kicad_pcb, Router-Rebooter.kicad_pcb_bom.csv, Router-Rebooter.kicad_pcb_positions.csv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]
2026-03-27 Tested relay
    [G5LE-1-VD_DC12.stp]
2026-03-27 Folder re-org
    [G5LE-1-VD_DC12.stp]
2026-03-27 Added ESP32 LED activity & DEBUG_MODE conditional
2026-03-27 Updated REV and date
    [Router-Rebooter.kicad_pcb, Router-Rebooter.kicad_sch]
2026-03-27 Modified component IDs to match
    Now R1 is for LED D1, R2 is for LED D2
    [Router-Rebooter.kicad_pcb, Router-Rebooter.kicad_pcb_bom.csv, Router-Rebooter.kicad_pcb_positions.csv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]
2026-03-27 Moved to Rev. B folder
    [Router-Rebooter.kicad_pcb, Router-Rebooter.kicad_pcb_bom.csv, Router-Rebooter.kicad_pcb_positions.csv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]
2026-03-27 Major redesign as Rev. C
    [Router-Rebooter.kicad_pcb, Router-Rebooter.kicad_pcb_bom.csv, Router-Rebooter.kicad_pcb_positions.csv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]
2026-03-27 Removed 3D model for 12V pin headers
    [Router-Rebooter.kicad_pcb]
2026-03-27 Added ESP32 LED activity & DEBUG_MODE flag
2026-03-28 Added WiFi status print to debug
2026-03-28 Small PCB adjustments
    [Router-Rebooter.kicad_pcb, Router-Rebooter.kicad_pcb_bom.csv, Router-Rebooter.kicad_pcb_positions.csv]
2026-03-29 Added ESP32 uptime statistic
2026-03-29 Re-oriented the PCB
    [Router-Rebooter.kicad_pcb, Router-Rebooter.kicad_pcb_bom.csv, Router-Rebooter.kicad_pcb_positions.csv]
2026-03-30 Added NTP timekeeping
    BUT ... there is a kernel panic during debug testing after power is cycled and wifi disconnect/reconnects ... suspect it might be due to HTTP GET requests
2026-03-30 Added last failed ping timestamp to HTTP status page
    [Experimental_version.ino]
2026-03-30 Resolved kernel panic after router reboot phase
    - Also cleaned up the code, tried to add useful comments everywhere
    - added use of F() to preserve RAM/heap usage
    [Experimental_version.ino]
2026-04-03 Added first NTP sync bool
    Need to avoid invalid 1/Jan/1970 timestamps ... really, the reboot/ping failure timestamp can't be any sooner than right now ... they can't be 1970, they can't be 2000, they can't be March 2026 ...
    Also added some padding/fixed width to the serial output logs just to make things look a bit nicer
    [Experimental_version.ino]
2026-04-05 Added reboot count & other minor tweaks
    [Experimental_version.ino]
2026-04-12 Artwork update
    [Router-Rebooter.kicad_pcb, Router-Rebooter.kicad_pcb_bom.csv, Router-Rebooter.kicad_pcb_positions.csv]
2026-04-15 Replaced D3, added D4
    [Router-Rebooter.kicad_pcb, Router-Rebooter.kicad_pcb_bom.csv, Router-Rebooter.kicad_pcb_positions.csv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]
2026-04-16 Fixed UTC-local TZ bug for failed pings
    [Experimental_version.ino]
2026-04-20 Added user text to PCB
    Clarify the empty zone on PCB is where the ESP32's WiFi antenna is so should be kept clear (this is for the PCB fab)
    [Router-Rebooter.kicad_pcb, Router-Rebooter.kicad_pcb_bom.csv, Router-Rebooter.kicad_pcb_positions.csv]
2026-04-30 Moved LED resistors to fix USB-C access to ESP32
    [Router-Rebooter.kicad_pcb, Router-Rebooter.kicad_pcb_bom.csv, Router-Rebooter.kicad_pcb_positions.csv]
2026-05-01 Modified ESP32 power bypass
    The ESP32 serial via USB wouldn't connect if the board was already powered via 12V - had to connect via USB first and then apply 12V power.
    So let's just have a simple 2-pin header to connect or disconnect the 5V regulator from the ESP32.
    [Router-Rebooter.kicad_pcb, Router-Rebooter.kicad_pcb_bom.csv, Router-Rebooter.kicad_pcb_positions.csv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]
2026-05-02 Updated from experimental version
    [1] Swapped d/m/y h:m:s to h:m:s d/m/y
    [2] Fixed Re(a)chability typo (thanks Brian)
    [Router-Rebooter.ino]
